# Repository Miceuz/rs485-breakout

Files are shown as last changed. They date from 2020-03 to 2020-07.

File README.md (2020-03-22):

# rs485-breakout
A tiny development board to quickly prototype RS485/Modbus devices

When building RS485/Modbus networks I have identified a need for a platform that would allow me to put various additional sensors or actuators on the network. Like relays to switch stuff, temperature, humidity sensors or other devices that don't have a native Modbus interface.

This board allows interfacing to different digital busses or analog devices.

## Features

* Robust RS485 interface
* ESD protection
* Extendable Modbus slave firmware
* I2C interface
* SPI interface
* 2 analog inputs
* PWM outputs
* 2x5 0.1' prototyping area
* Small form factor allowing PCB integration or inline integration into cable assembly

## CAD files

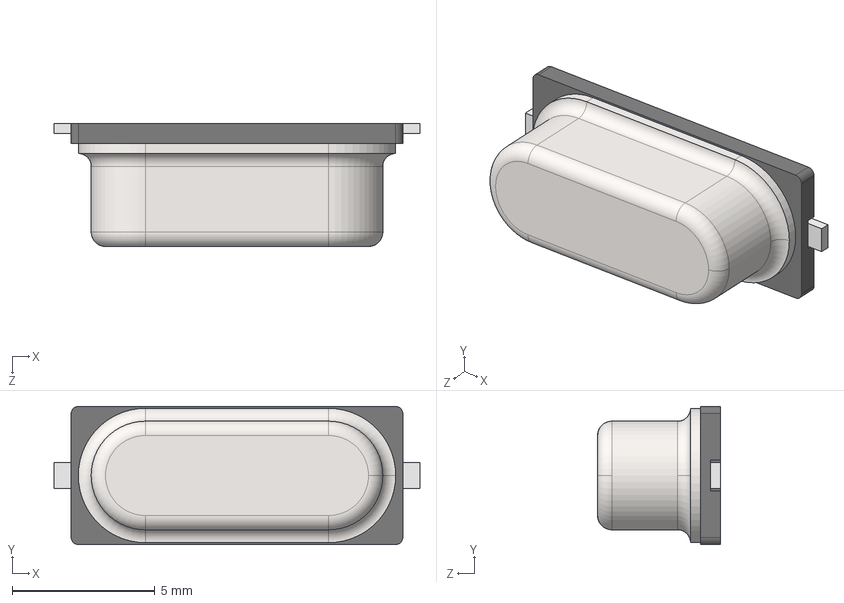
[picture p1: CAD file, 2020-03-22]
3d/User Library-Crystal HC49_US-SM.STEP
12.8 x 4.83 x 4.30 mm

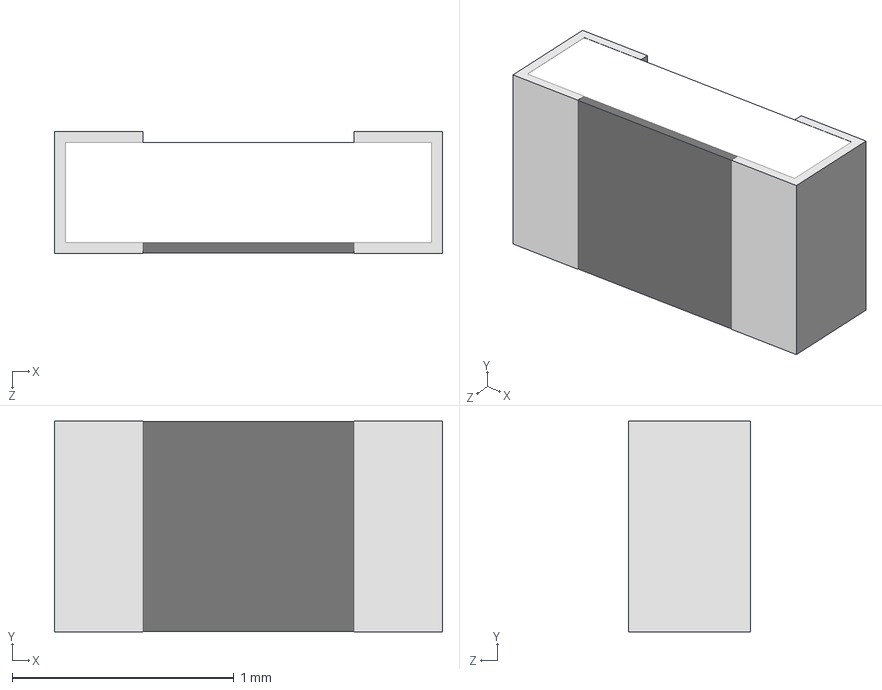
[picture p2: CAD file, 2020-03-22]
3d/User Library-RES_SMD-1.STEP
1.75 x 0.95 x 0.55 mm

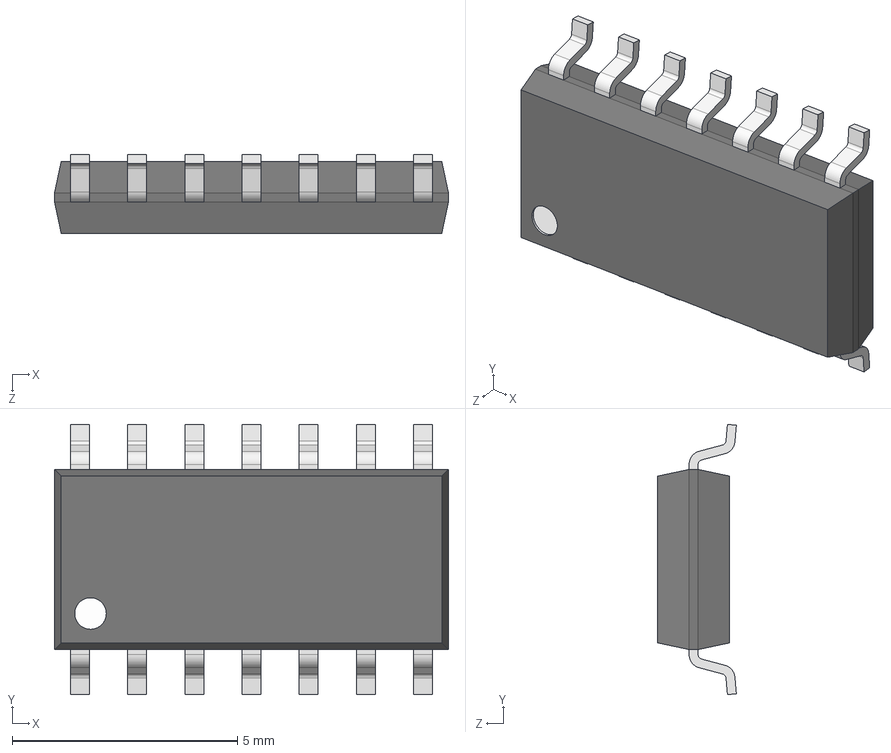
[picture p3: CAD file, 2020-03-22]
3d/User Library-SOIC-14.STEP
8.75 x 6.00 x 1.75 mm

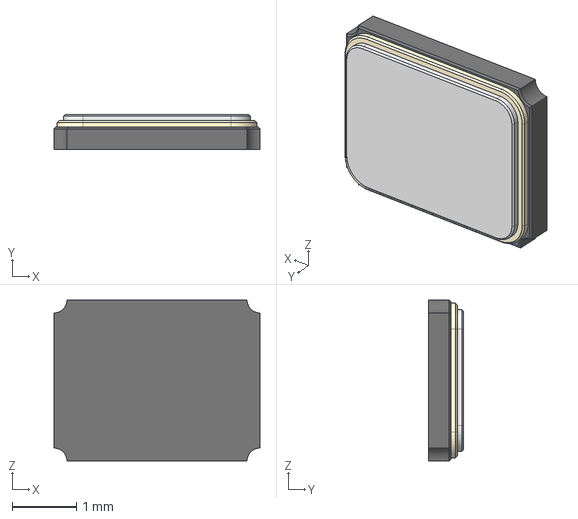
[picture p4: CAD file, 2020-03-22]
3d/CRY_SMD3225.STEP
3.20 x 0.55 x 2.50 mm

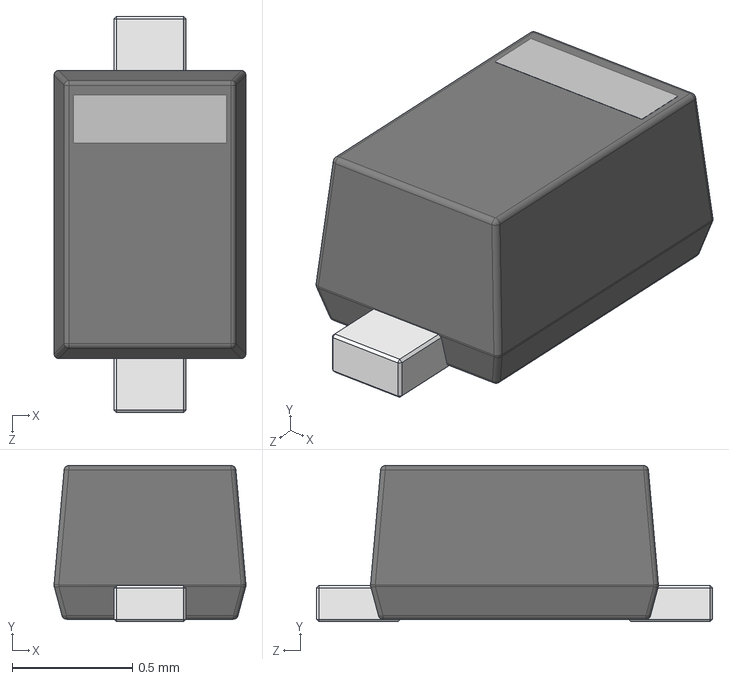
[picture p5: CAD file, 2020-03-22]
3d/User Library-SOD523-2.STEP
0.8 x 0.651 x 1.65 mm

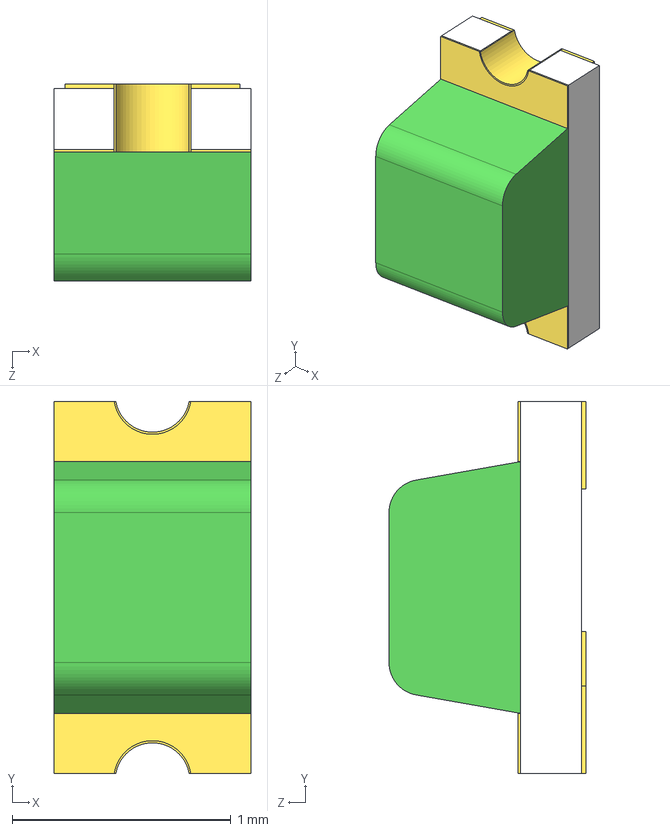
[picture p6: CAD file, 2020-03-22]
3d/User Library-LTST-C190GKT.STEP
0.9 x 1.70 x 0.9 mm
User Library-LTST-C190GKT_Pad005
User Library-LTST-C190GKT_Pad001
User Library-LTST-C190GKT_Pad004
User Library-LTST-C190GKT_Pad003
User Library-LTST-C190GKT_Lens
User Library-LTST-C190GKT_Pad

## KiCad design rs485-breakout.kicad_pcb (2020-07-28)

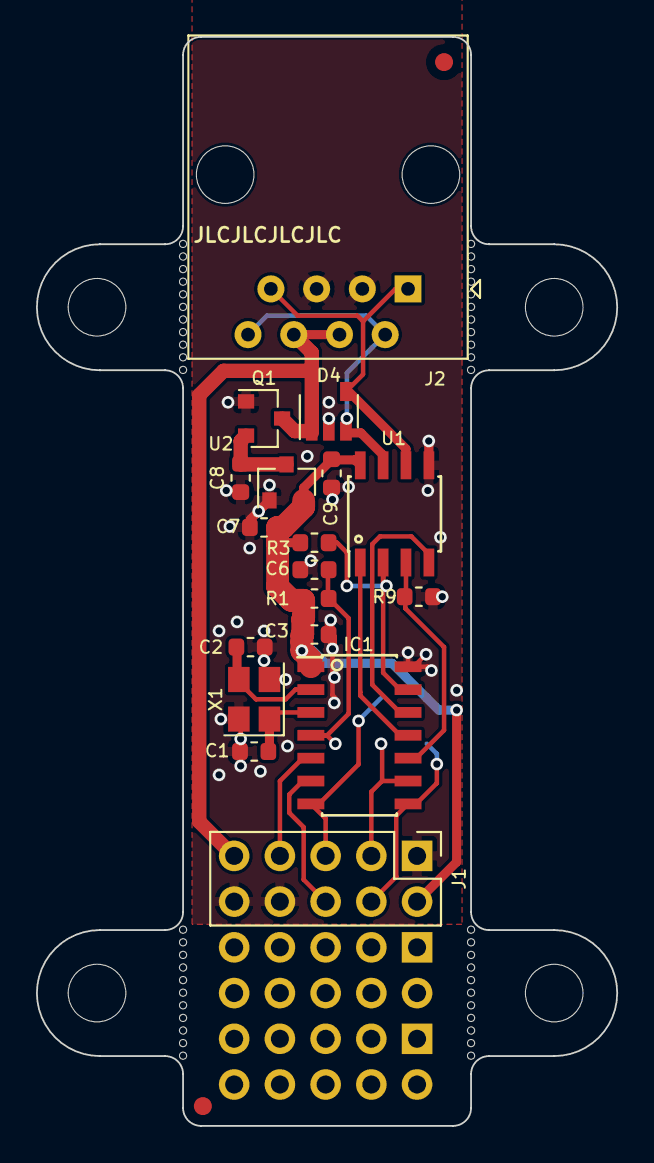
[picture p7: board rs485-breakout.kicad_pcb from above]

Board: 2 copper layers, 32.2 x 60.5 mm, 27 parts (1 on the bottom side), 18 nets.

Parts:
C1, C2: 13p; C_0603_1608Metric
C3, C6, C7, C8, C9: 1u; C_0603_1608Metric
D4: NUP4004M5T1G; SOT-23-5
FID1, FID2: Fiducial; Fiducial_1mm_Dia_2mm_Outer
H1, H2, H3, H4: MountingHole; MountingHole_3.2mm_M3
IC1: ATTINY441-SSU; SOIC-14_3.9x8.7mm_Pitch1.27mm
J1, J3, J4: Conn_01x08; Pin_Header_Straight_2x05_Pitch2.54mm
J2: RJ45; RJ45_Amphenol_54602-x08_Horizontal
P1: CONN_02X03; Pin_Header_Straight_2x03
Q1: Q_PMOS_GSD; SOT-23
R1, R3, R9: 10k; R_0603_1608Metric
U1: SN65HVD72; SOIC-8_3.9x4.9mm_Pitch1.27mm
U2: MCP1702; SOT-23
X1: 16MHz; Crystal_SMD_3225-4pin_3.2x2.5mm

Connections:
+3V3: C3.1, C7.1, C9.1, IC1.1, J1.2, P1.2, R1.2, R3.1, U1.8, U2.2
/ADC7/OC2B: IC1.6, J1.6
/ADC8/OC2A: IC1.5, J1.7
/MISO: IC1.8, J1.4, P1.1
/MOSI/SDA: IC1.7, J1.5, P1.4
/RESET: C6.1, IC1.4, P1.5, R1.1
/RS485A: D4.4, J2.1, J2.7, U1.6
/RS485B: D4.3, J2.2, J2.8, U1.7
/RS485_DRIVER_ENABLE: IC1.10, R9.1, U1.3
/RX: IC1.11, U1.1
/SCK/SCL: IC1.9, J1.3, P1.3
/TX: IC1.12, U1.4
/~RS485_READER_ENABLE: IC1.13, R3.2, U1.2
GND: C1.2, C2.2, C3.2, C6.2, C7.2, C8.2, C9.2, D4.2, IC1.14, J1.1, J1.8, J1.10, J2.3, J2.5, P1.6, Q1.1, R9.2, U1.5, U2.1, X1.2, X1.4
unnamed: C1.1, IC1.3, X1.1
unnamed: C2.1, IC1.2, X1.3
unnamed: C8.1, Q1.2, U2.3
VCC: D4.1, D4.5, J1.9, J2.4, J2.6, Q1.3

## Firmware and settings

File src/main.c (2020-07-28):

/**
Version history:

0x1000 -- initial
0x1001 -- bugfix, allow address change
0x1100 -- new feature - watchdog timer always on, fix sleep times, add firmware
version input register

Versioning number structure:
0x[major version, 4bit][feature update, 4bit][bugfix 8bit]
*/
#define FIRMWARE_VERSION 0x1100

#include <avr/eeprom.h>
#include <avr/interrupt.h>
#include <avr/io.h>
#include <avr/sleep.h>
#include <inttypes.h>
#include <measurement.h>
#include <stdbool.h>
#include <stdio.h>
#include <util/delay.h>

#include "modbus.h"
#include "model.h"

#define DRIVER_ENABLE PA3
#define READER_ENABLE PA0

volatile t_InputRegisters inputRegisters;

volatile t_HoldingRegisters holdingRegisters;

uint8_t eeprom_address EEMEM = 1;
uint8_t eeprom_baudIdx EEMEM = 4;
uint8_t eeprom_parityIdx EEMEM = 0;
uint16_t eeprom_measurementIntervalMs EEMEM = 500;

uint8_t temp = 0;

inline static void serialReaderDisable() { PORTA |= _BV(READER_ENABLE); }

inline static void serialDriverDisable() { PORTA &= ~_BV(DRIVER_ENABLE); }

inline static void serialDriverEnable() {
  serialReaderDisable();
  PORTA |= _BV(DRIVER_ENABLE);
}

inline static void serialReaderEnable() {
  serialDriverDisable();
  PORTA &= ~_BV(READER_ENABLE);
}

void transceiver_txen(void) { serialDriverEnable(); }

void transceiver_rxen(void) { serialReaderEnable(); }

inline static void reset() {
  WDTCSR = _BV(WDE);  // reset in 16ms
  while (1)
    ;
}

inline static bool isValidAddress(uint8_t address) {
  return address > 0 && address < 248;
}

inline static bool isValidBaud(uint8_t baudIdx) {
  return baudIdx >= 0 && baudIdx < 8;
}

inline static bool isValidParity(uint8_t parityIdx) {
  return parityIdx >= 0 && parityIdx < 3;
}

static inline bool isAddressRegisterSet() {
  return 0 == modbusGetRegisterNumber();
}

static inline bool isBaudRegisterSet() {
  return 1 == modbusGetRegisterNumber();
}

static inline bool isParityRegisterSet() {
  return 2 == modbusGetRegisterNumber();
}

static inline bool isMeasurementIntervalRegisterSet() {
  return 3 == modbusGetRegisterNumber();
}

inline static bool isSleepTimeSet() {
  return 0 != holdingRegisters.asStruct.sleepTimeS;
}

static inline bool isGpioRegisterSet() {
  return 5 == modbusGetRegisterNumber();
}

void saveByteAndReset(uint8_t *eeprom, uint8_t value) {
  eeprom_write_byte(eeprom, value);
  while (!modbusIsIdle()) {
    // wait
  }
  reset();
}

/**
 * 0 - SCL/SCK/PA4
 * 1 - MISO/PA5
 * 2 - MOSI/SDA/PA6
 **/

static inline void gpioControll() {
  DDRA |= _BV(PA4) | _BV(PA5) | _BV(PA6);
  if (holdingRegisters.asStruct.gpio & 0x00000001) {
    PORTA |= _BV(PA4);
  } else {
    PORTA &= ~_BV(PA4);
  }
  if (holdingRegisters.asStruct.gpio & 0x00000002) {
    PORTA |= _BV(PA5);
  } else {
    PORTA &= ~_BV(PA5);
  }
  if (holdingRegisters.asStruct.gpio & 0x00000004) {
    PORTA |= _BV(PA6);
  } else {
    PORTA &= ~_BV(PA6);
  }
}

void modbusGet(void) {
  if (modbusIsFrameAvailable()) {
    switch (modbusGetFunctionCode()) {
      case fcReadHoldingRegisters: {
        modbusExchangeRegisters(holdingRegisters.asArray, 6);
      } break;

      case fcReadInputRegisters: {
        modbusExchangeRegisters(inputRegisters.asArray, 3);
      } break;

        //            case fcPresetMultipleRegisters:
      case fcPresetSingleRegister: {
        modbusExchangeRegisters(holdingRegisters.asArray, 6);
        if (isAddressRegisterSet()) {
          if (isValidAddress(holdingRegisters.asStruct.address)) {
            saveByteAndReset(&eeprom_address,
                             holdingRegisters.asStruct.address);
          }
        } else if (isBaudRegisterSet()) {
          if (isValidBaud(holdingRegisters.asStruct.baud)) {
            saveByteAndReset(&eeprom_baudIdx, holdingRegisters.asStruct.baud);
          }
        } else if (isParityRegisterSet()) {
          if (isValidParity(holdingRegisters.asStruct.parity)) {
            saveByteAndReset(&eeprom_parityIdx,
                             holdingRegisters.asStruct.parity);
          }
        } else if (isMeasurementIntervalRegisterSet()) {
          eeprom_write_word(&eeprom_measurementIntervalMs,
                            holdingRegisters.asStruct.measurementIntervalMs);
        } else if (isGpioRegisterSet()) {
          gpioControll();
        }
      } break;

      default: {
        modbusSendException(ecIllegalFunction);
      } break;
    }
  }
}

volatile uint16_t sleepTimes = 0;
volatile uint16_t secondsToSleep = 0;

#define WDT_TIMEOUT_8S 0b00100001
#define WDT_TIMEOUT_4S 0b00100000
#define WDT_TIMEOUT_2S 0b00000111
#define WDT_TIMEOUT_1S 0b00000110
#define WDT_TIMEOUT_05S 0b00000101
#define WDT_TIMEOUT_025S 0b00000100
#define WDT_TIMEOUT_0125S 0b00000011
#define WDT_TIMEOUT_64MS 0b00000010
#define WDT_TIMEOUT_32MS 0b00000001
#define WDT_TIMEOUT_16MS 0b00000000
#define WDT_TIMEOUT_DEFAULT WDT_TIMEOUT_0125S

void wdtSetTimeout(uint8_t timeout) {
  timeout |= _BV(WDE);
  CCP = 0xD8;
  WDTCSR = timeout;
}

inline static void wdtInterruptEnable() { WDTCSR |= _BV(WDIE); }

inline static void wdtInterruptDisable() { WDTCSR &= ~_BV(WDIE); }

ISR(WDT_vect) {
  // Just wakeup. For some reason enabling WDT interrupt inside of ISR does not
  // work, so we do it in sleep loop
}

static inline void sleepSetup() {
  if (secondsToSleep >= 8) {
    wdtSetTimeout(WDT_TIMEOUT_8S);
    sleepTimes = secondsToSleep / 8;
    secondsToSleep = secondsToSleep - sleepTimes * 8;

  } else if (secondsToSleep >= 4) {
    wdtSetTimeout(WDT_TIMEOUT_4S);
    sleepTimes = 1;
    secondsToSleep = secondsToSleep - 4;

  } else if (secondsToSleep >= 2) {
    wdtSetTimeout(WDT_TIMEOUT_2S);
    sleepTimes = 1;
    secondsToSleep = 1;  // secondsToSleep - 2;

  } else if (secondsToSleep == 1) {
    wdtSetTimeout(WDT_TIMEOUT_1S);
    sleepTimes = 1;
    secondsToSleep = secondsToSleep - 1;
  }
}

void sleep() {
  measurementReset();
  PORTA = 0;

  serialDriverDisable();
  serialReaderDisable();
  UCSR0B &= ~_BV(TXEN0);

  secondsToSleep = holdingRegisters.asStruct.sleepTimeS;
  holdingRegisters.asStruct.sleepTimeS = 0;

  sleepSetup();
  set_sleep_mode(SLEEP_MODE_PWR_DOWN);

  asm("WDR");
  while ((sleepTimes > 0) || (secondsToSleep > 0)) {
    while (sleepTimes > 0) {
      wdtInterruptEnable();
      sleep_mode();
      sleepTimes--;
    }
    sleepSetup();
  }

  wdtInterruptDisable();
  wdtSetTimeout(WDT_TIMEOUT_DEFAULT);

  performMeasurement(&inputRegisters);

  UCSR0B |= _BV(TXEN0);
  serialReaderEnable();
}

inline static void saveConfig() {
  eeprom_write_byte(&eeprom_address, holdingRegisters.asStruct.address);
  eeprom_write_byte(&eeprom_baudIdx, holdingRegisters.asStruct.baud);
  eeprom_write_byte(&eeprom_parityIdx, holdingRegisters.asStruct.parity);
  eeprom_write_word(&eeprom_measurementIntervalMs,
                    holdingRegisters.asStruct.measurementIntervalMs);
}

inline static void loadConfig() {
  inputRegisters.asStruct.fwVersion = FIRMWARE_VERSION;
  holdingRegisters.asStruct.sleepTimeS = 0;

  temp = eeprom_read_byte(&eeprom_address);

  if (isValidAddress(temp)) {
    holdingRegisters.asStruct.address = temp;
  } else {
    holdingRegisters.asStruct.address = 1;
  }

  temp = eeprom_read_byte(&eeprom_baudIdx);
  if (temp >= 0 && temp < 8) {
    holdingRegisters.asStruct.baud = temp;
  } else {
    holdingRegisters.asStruct.baud = 4;
  }

  temp = eeprom_read_byte(&eeprom_parityIdx);
  if (temp >= 0 && temp < 3) {
    holdingRegisters.asStruct.parity = temp;
  } else {
    holdingRegisters.asStruct.parity = 0;
  }

  holdingRegisters.asStruct.measurementIntervalMs =
      eeprom_read_word(&eeprom_measurementIntervalMs);
  if (65535 == holdingRegisters.asStruct.measurementIntervalMs) {
    holdingRegisters.asStruct.measurementIntervalMs = 500;
  }
}

void main(void) {
  wdtSetTimeout(WDT_TIMEOUT_DEFAULT);

  DDRA |= _BV(DRIVER_ENABLE);
  DDRA |= _BV(READER_ENABLE);

  // DDRA |= _BV(PA3);
  // PINA |= _BV(PA3);
  // _delay_ms(100);
  // PINA |= _BV(PA3);

  loadConfig();

  modbusSetAddress(holdingRegisters.asStruct.address);
  modbusInit(holdingRegisters.asStruct.baud, holdingRegisters.asStruct.parity);

  adcSetup();
  sei();
  timer1msStart(&(holdingRegisters.asStruct.measurementIntervalMs));

  performMeasurement(&inputRegisters);

  serialReaderEnable();

  while (1) {
    processMeasurements(&inputRegisters);
    modbusGet();

    if (isSleepTimeSet() && modbusIsIdle() && modbusIsTXComplete()) {
      sleep();
    }
    asm("WDR");
  }
}

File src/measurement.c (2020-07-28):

#include <avr/interrupt.h>
#include <avr/io.h>
#include <stdbool.h>

#include "model.h"

#define CHANNEL_ADC7 7
#define CHANNEL_ADC8 8

#define STATE_MEASUREMENT_OFF 0
#define STATE_MEASUREMENT_STABILIZE 1
#define STATE_MEASUREMENT_IN_PROGRESS 2
uint8_t measurementState = STATE_MEASUREMENT_OFF;

volatile uint16_t milliseconds = 0;
volatile uint16_t *measurementTimeoutMs;
uint8_t temp;

inline static void adcEnable() { ADCSRA |= _BV(ADEN); }

inline static void adcDisable() { ADCSRA &= ~_BV(ADEN); }

void adcSetup() {
  ADCSRA = _BV(ADEN) | _BV(ADPS2) | _BV(ADPS0);
  ADMUXB = 0;
  DIDR0 |= _BV(ADC7D);
  // | _BV(ADC0D) | _BV(ADC1D) | _BV(ADC2D) | _BV(ADC4D) |
  // _BV(ADC6D) | _BV(ADC8D);
  //  | _BV(ADC8D); //Don't disable digital buffer on ADC8D as that disables
  //  UART (woot? silicon errata?)

  ACSR0A = _BV(ACD0);  // disable comparators
  ACSR1A = _BV(ACD1);

  adcDisable();
}

uint16_t adcReadChannel(uint8_t channel) {
  ADMUXA = channel;
  ADCSRA |= _BV(ADSC);
  loop_until_bit_is_clear(ADCSRA, ADSC);
  uint16_t ret = ADC;
  return ret;
}

inline static bool isTimeToMeasure() {
  return milliseconds > *measurementTimeoutMs;
}

inline static bool isTimeToStabilizeOver() {
  return milliseconds > *measurementTimeoutMs + 2;
}

inline static void startMeasurementTimer() {
  TIMSK1 &= ~_BV(OCIE1A);
  milliseconds = 0;
  TCNT1 = 0;
  TIMSK1 |= _BV(OCIE1A);
}

void timer1msStart(volatile uint16_t *ptrToTimeout) {
  measurementTimeoutMs = ptrToTimeout;
  OCR1A = (uint16_t)16000L;
  TIMSK1 |= _BV(OCIE1A);
  TCCR1B = _BV(CS10) | _BV(WGM12);
}

ISR(TIMER1_COMPA_vect) { milliseconds++; }

void measurementReset() {
  adcDisable();
  startMeasurementTimer();
  measurementState = STATE_MEASUREMENT_OFF;
}

bool isMeasurementInProgress() {
  return measurementState != STATE_MEASUREMENT_OFF;
}

inline static void measurementPeripheryOn() { adcEnable(); }

void processMeasurements(t_InputRegisters *inputRegisters) {
  switch (measurementState) {
    case STATE_MEASUREMENT_OFF:
      if (isTimeToMeasure()) {
        measurementPeripheryOn();
        measurementState = STATE_MEASUREMENT_STABILIZE;
      }
      break;

    case STATE_MEASUREMENT_STABILIZE:
      if (isTimeToStabilizeOver()) {
        measurementState = STATE_MEASUREMENT_IN_PROGRESS;
      }
      break;

    case STATE_MEASUREMENT_IN_PROGRESS: {
      uint16_t adc7 = adcReadChannel(CHANNEL_ADC7);
      uint16_t adc8 = adcReadChannel(CHANNEL_ADC8);
      inputRegisters->asStruct.adc7 = adc7;
      inputRegisters->asStruct.adc8 = adc8;

      measurementReset();
    } break;
  }
}

inline static void forceStartMeasurement() {
  cli();
  milliseconds = *measurementTimeoutMs + 1;
  sei();
  measurementPeripheryOn();
  measurementState = STATE_MEASUREMENT_STABILIZE;
}

void performMeasurement(t_InputRegisters *inputRegisters) {
  forceStartMeasurement();
  while (isMeasurementInProgress()) {
    processMeasurements(inputRegisters);
  }
}

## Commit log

2020-03-22 Initial commit - v1.0 PCB is almost ready for production
    [CRY_SMD3225.STEP, User Library-CAP_SMD-1.STEP, User Library-Crystal HC49_US-SM.STEP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]
2020-03-22 Update version numbers in schematics and PCB meta info
    [rs485-breakout.kicad_pcb, rs485-breakout.sch]
2020-06-18 Update fuses - higher BOD level and don't output clock on a pin
2020-06-18 Don't disable digital buffer on ADC8D as that disables UART (woot? silicon errata?)
    [measurement.c]
2020-07-28 fix programming header silkscreen
    [rs485-breakout.kicad_pcb]
2020-07-28 Pass input registers explicitely by reference as that is not the case any more after the compiler change.
